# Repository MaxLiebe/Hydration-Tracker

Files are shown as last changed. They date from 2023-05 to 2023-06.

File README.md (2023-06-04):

# DIYCie Hydration Tracker
A device that can keep track of your hydration! 
It uses a 1kg load cell to detect the presence (and possibly fullness) of one's glass or bottle, and can perform various actions based on that. 
The main feature for the Hydration Tracker is keeping track of the time it takes for one to down their drink. The current list of planned and completed features is as follows:

- [X] Successfully detect the presence of a glass, and start/stop the timer accordingly.
- [X] Using the button on the front, allow the user to select different modes (e.g. down a bottle, down a glass, down a bottle of Smirnoff Ice, etc.)
- [X] Different LED ring animations depending on which mode.
- [ ] Allow the user to save the time it took to down a drink in a leaderboard.
- [X] Host a web page for entering a leaderboard score.
- [ ] Detect how full a glass is for games like "Pannetje-Pannetje" or a "Pitcheradt" (likely difficult to implement)

More features may be implemented if the hardware allows it! If you have any suggestions, please suggest them as an [issue](https://github.com/MaxLiebe/Hydration-Tracker/issues/new).

# Installation
For the installation instructions, please refer to the manual hosted on the Proto wiki. (no link yet).

# List of components
Please find the list of components in the manual (no link yet).

# 3d printing
The 3d printed units used can be found in the .stl folder. For the workshop, they were printed using 10% infill, PLA and no support.

# Acknowledgement and inspiration
This project was inspired by the Enschede-famous [AdtMeister](https://adtmeister.com/). DIYCie or S.A. Proto does not have any affiliations with AdtMeister.

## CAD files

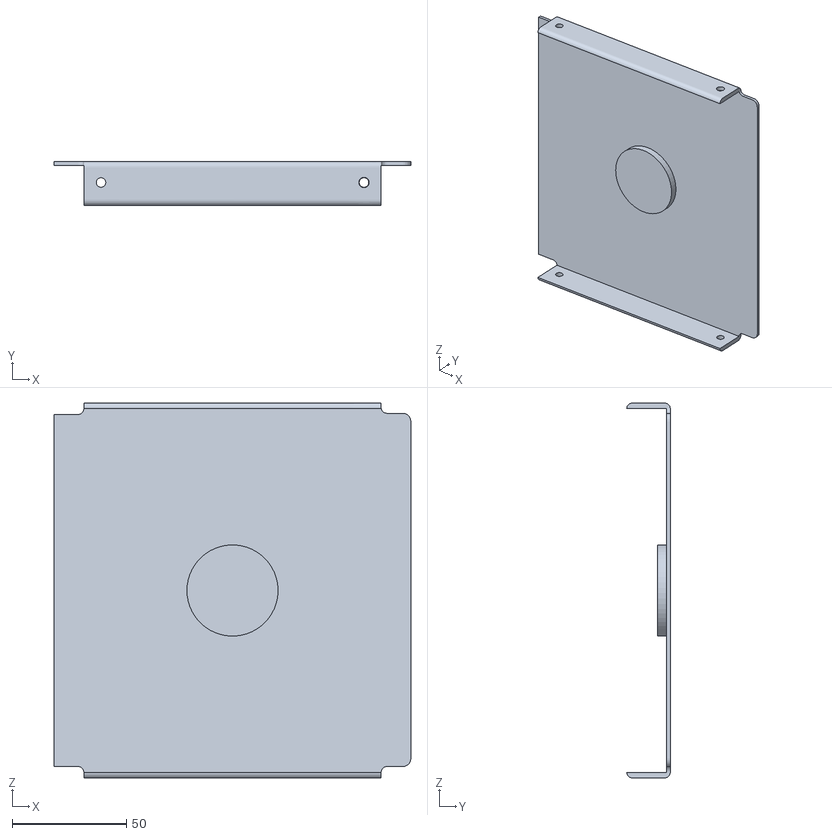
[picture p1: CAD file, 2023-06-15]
stl/cap.stl
156.0 x 19.1 x 164.0

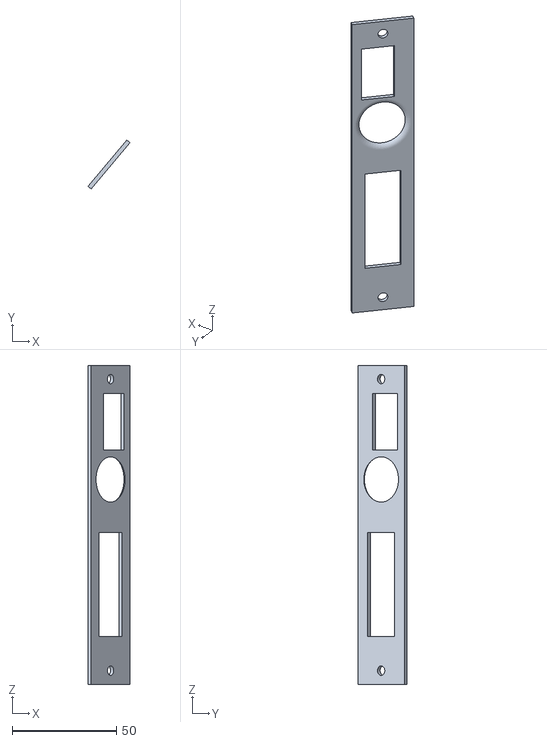
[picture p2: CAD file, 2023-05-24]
stl/front-cover.stl
20.2 x 23.5 x 153.0

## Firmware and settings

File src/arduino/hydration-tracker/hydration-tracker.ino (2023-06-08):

//IMPORT LIBRARIES
#include <FastLED.h>
#include "HX711.h"
#include <TM1637Display.h>
#include <Wire.h>
#include <SSD1306.h>
#include <qrcodeoled.h>
#include <WiFi.h>
#include <AsyncTCP.h>
#include <ESPAsyncWebServer.h>
#include "DNSServer.h"
#include "FS.h"
#include "SD.h"
#include "SPI.h"
#include <EEPROM.h>

#include "fonts.h"
#include "logo.h"

//Use debug mode?
//#define DEBUG //uncomment if you want to use debug mode (for calibration)

//SCREEN
#define SCREEN_ADDRESS 0x3C
#define OLED_SDA 17
#define OLED_SCK 16
SSD1306 display(SCREEN_ADDRESS, OLED_SDA, OLED_SCK, GEOMETRY_128_64);
QRcodeOled qrcode(&display);

//LED RING
#define RING_DATA_PIN 14
#define LED_TYPE WS2812B
#define COLOR_ORDER GRB
#define NUM_LEDS 24
#define BRIGHTNESS 200
#define MIN_BRIGHTNESS 0
CRGB ringLeds[NUM_LEDS];

//LOAD CELL
#define HX711_SCK 5
#define HX711_DT 3
#define LOAD_CELL_THRESHOLD 75000 //can be calibrated yourself. we'd recommend leaving it at this value
#define LOAD_CELL_CALIBRATED_VALUE -330000 //same as above
HX711 loadCell;

//TIMER
#define TIMER_CLK 2
#define TIMER_DIO 1
TM1637Display timer(TIMER_CLK, TIMER_DIO);
uint8_t TIMER_BLANK[4];

//SD Card
#define SD_CS_PIN        12
#define SD_CLK_PIN       11
#define SD_MOSI_PIN      9
#define SD_MISO_PIN      7
#define SD_FREQ          80000000
SPIClass spi = SPIClass(HSPI);

//MODE BUTTON
#define MODE_BUTTON_PIN 21

//TIMER MODES
#define SECONDS_HUNDREDTHS 0
#define MINUTES_SECONDS 1

//TIMER STATES
#define BOOTING -1
#define WAITING_FOR_THRESHOLD 0
#define THRESHOLD_REACHED 1
#define TIMER_RUNNING 2
#define TIMER_STOPPED 3

#define BOOT_TIME 4000
#define ONE_MINUTE 60000
#define MINIMUM_TIME 700

//ANIMATION STATES
#define ANIMATION_BOOT 0
#define ANIMATION_IDLE 1
#define ANIMATION_TIMER_PRIMED 2
#define ANIMATION_TIMER_STARTED 3
#define ANIMATION_TIMER_RUNNING 4
#define ANIMATION_TIMER_STOPPED 5
#define ANIMATION_MODUS_STATE 6

#define ANIMATION_SPEED_DRINKING 25
#define BRIGHTNESS_STEP_DRINKING 15

#define PULSE_DURATION 1000  // Duration of the pulse in milliseconds

//EEPROM
#define EEPROM_SIZE 4 //4 bytes to save the calibrated value long

//MODE STATES
#define NUMBER_OF_MODES 3
const String modes[NUMBER_OF_MODES] = {
  "beer_glass", "beer_rietadt", "ice"
};
const String modeNames[NUMBER_OF_MODES] = {
  "Beer out \n of glass", "Beer with \n straw", "Schmirnoff \n Ice"
};
const uint32_t modeColors[NUMBER_OF_MODES] = {
  CRGB::Yellow, CRGB::Green, CRGB::LightBlue
};

//WIFI CREDENTIALS FOR LEADERBOARD
const char* ssid = "HydrationTracker";
const char* password = ""; //optional, more effort for drunk people tho
#define LOCAL_IP_URL "http://4.3.2.1"

//WIFI SERVER
AsyncWebServer server(80);
DNSServer dnsServer;
String header;

//VARIABLES
unsigned long timerStartedMs = 0;
unsigned long timeElapsed = 0;
unsigned long animationStarted = 0;
int timerState = BOOTING;
int modeState = 0;
int animationState = ANIMATION_BOOT;
bool leaderboardEnabled = true;

bool pulseActive = true;
bool canSwitchMode = true;
bool showQR = false;
String drinkStatus = "Waiting for drink";

unsigned long lastDebounceTime = 0;  // the last time the output pin was toggled
unsigned long debounceDelay = 200;   // the debounce time; increase if the output flickers

// Define the current brightness and pulsation direction
uint8_t minBrightnessDrinking = MIN_BRIGHTNESS;
int8_t pulsationDirectionDrinking = 1;

// Define variables for timing
unsigned long previousMillisDrinking = 0;
unsigned long intervalDrinking = ANIMATION_SPEED_DRINKING;

void setup() {
  Serial.begin(9600);
  //initialize the LED ring with FastLED, and turn off all the LEDs
  FastLED.addLeds<LED_TYPE, RING_DATA_PIN, COLOR_ORDER>(ringLeds, NUM_LEDS).setCorrection(TypicalLEDStrip);
  FastLED.setBrightness(BRIGHTNESS);
  FastLED.clear();
  FastLED.show();

  //initialize the load cell
  loadCell.begin(HX711_DT, HX711_SCK);

  //initialize the 7 segment timer
  timer.setBrightness(0xff);
  encodeMsToTimer(0);

  //set the button to use the inbuilt pullup resistor
  pinMode(MODE_BUTTON_PIN, INPUT_PULLUP);

  //init and clear the display
  Wire.begin(OLED_SDA, OLED_SCK);
  display.setColor(WHITE);
  display.setFont(Roboto_Black_14);
  display.init();
  qrcode.init();
  display.clear();

  //show the splash screen
  display.drawXbm(0, 0, LOGO_WIDTH, LOGO_HEIGHT, LOGO_BITS);
  display.flipScreenVertically();
  display.display();

  //setup sd card
  spi.begin(SD_CLK_PIN, SD_MISO_PIN, SD_MOSI_PIN, SD_CS_PIN); 
  if (!SD.begin(SD_CS_PIN, spi, SD_FREQ)) {
    //SD card initialisation failed, don't bother with setting up a wifi hotspot.
    leaderboardEnabled = false;
    return;
  }

  //setup wifi access point
  WiFi.mode(WIFI_STA);
  IPAddress Ip(4, 3, 2, 1);
  IPAddress NMask(255, 255, 255, 0);
  WiFi.softAPConfig(Ip, Ip, NMask);
  WiFi.softAP(ssid, password);
  IPAddress IP = WiFi.softAPIP();

  dnsServer.start(53, "*", IP);
  server.on("/", HTTP_GET, [](AsyncWebServerRequest *request){
    //request->send(200, "text/plain", "Hello, world");
    request->send(SD, "/index.html", "text/html");
  });
  server.on("/generate_204", [](AsyncWebServerRequest *request) { request->redirect(LOCAL_IP_URL); });
  server.on("/redirect", [](AsyncWebServerRequest *request) { request->redirect(LOCAL_IP_URL); });			   // microsoft redirect
	server.on("/hotspot-detect.html", [](AsyncWebServerRequest *request) { request->redirect(LOCAL_IP_URL); });  // apple call home
	server.on("/canonical.html", [](AsyncWebServerRequest *request) { request->redirect(LOCAL_IP_URL); });	   // firefox captive portal call home
	server.on("/success.txt", [](AsyncWebServerRequest *request) { request->send(200); });					   // firefox captive portal call home
	server.on("/ncsi.txt", [](AsyncWebServerRequest *request) { request->redirect(LOCAL_IP_URL); });			   // windows call home
  server.serveStatic("/", SD, "/");
  
  server.begin();
}

void loop() {
  #ifndef DEBUG
  if(!showQR) {
    display.setTextAlignment(TEXT_ALIGN_CENTER);
    display.clear();
    display.drawString(64, 12, drinkStatus);
    display.drawString(64, 30, "Mode: " + modeNames[modeState]);
    display.display();
  }
  #endif

  if ((millis() - lastDebounceTime) > debounceDelay) {
    if (digitalRead(MODE_BUTTON_PIN) == 0) {
      if(timerState == TIMER_STOPPED) {
        timerState = WAITING_FOR_THRESHOLD;
        animationState = ANIMATION_IDLE;
        canSwitchMode = true;
        lastDebounceTime = millis();
        showQR = false;
      }else if(canSwitchMode){
        lastDebounceTime = millis();  //set the current time
        modeState += 1;
        animationStarted = millis();
        animationState = ANIMATION_MODUS_STATE;
        showQR = false;
      }
    }
  }
  if (modeState > NUMBER_OF_MODES - 1) {
    modeState = 0;
  }

  switch (timerState) {
    case BOOTING:
      canSwitchMode = true;
      if (millis() > BOOT_TIME) {
        timerState = WAITING_FOR_THRESHOLD;
        animationState = ANIMATION_IDLE;
        switch(SD.cardType()) {
          case CARD_NONE: {
            display.drawString(64, 50, "No SD card found");
            leaderboardEnabled = false;
            break;
          }
        }
        display.display();
      }
      break;
    case TIMER_RUNNING:
      timeElapsed = millis() - timerStartedMs;
      if(timeElapsed > MINIMUM_TIME) encodeMsToTimer(timeElapsed);
      break;
  }

  if (loadCell.is_ready()) {
    int weightValue = loadCell.get_value(1);
    #ifdef DEBUG
    display.clear();
    display.setTextAlignment(TEXT_ALIGN_LEFT);
    display.drawString(0, 6, String(weightValue));
    display.display();
    #endif

    //becomes true if something is detected on the load cell (the weight is above the threshold)
    bool thresholdMet = LOAD_CELL_CALIBRATED_VALUE - weightValue < -LOAD_CELL_THRESHOLD || LOAD_CELL_CALIBRATED_VALUE - weightValue > LOAD_CELL_THRESHOLD;

    switch (timerState) {
      case WAITING_FOR_THRESHOLD:
        if (thresholdMet && millis() - lastDebounceTime > debounceDelay) {
          canSwitchMode = false;
          lastDebounceTime = millis();
          timerState = THRESHOLD_REACHED;
          animationState = ANIMATION_TIMER_PRIMED;
          animationStarted = millis();
          encodeMsToTimer(0);
          drinkStatus = "Ready?";
          showQR = false;
        }
        break;
      case THRESHOLD_REACHED:
        if (!thresholdMet && millis() - lastDebounceTime > debounceDelay) {
          timerState = TIMER_RUNNING;
          timerStartedMs = millis();
          canSwitchMode = false;
          animationState = ANIMATION_TIMER_RUNNING;
          drinkStatus = "Go!";
        }
        break;
      case TIMER_RUNNING:
        if (thresholdMet) { 
          if(millis() - timerStartedMs >= MINIMUM_TIME) {
            timerState = TIMER_STOPPED;
            animationState = ANIMATION_TIMER_STOPPED;
            animationStarted = millis();
            drinkStatus = "Waiting for drink";
            if(leaderboardEnabled) {
              char secret[10];
              generateRandomDigits(secret, 10);
              char url[100];
              sprintf(url, "http://4.3.2.1?t=%i&s=%.10s", timeElapsed, secret);
              qrcode.create(url);
              showQR = true;
            }
          }
        }
        break;
    }
  }

  //switch statement to manage what animation is being displayed on the LED ring
  switch (animationState) {
    case ANIMATION_MODUS_STATE:
      {
        if (millis() - animationStarted > debounceDelay * 2) {
          animationState = ANIMATION_IDLE;
        }
        modusSwitch();
        break;
      }
    case ANIMATION_BOOT:
      {
        bootAnimation();
        break;
      }
    case ANIMATION_IDLE:
      {
        idleRingAnimation();
        break;
      }
    case ANIMATION_TIMER_PRIMED:
      {
        timerPrimedAnimation();
        break;
      }
    case ANIMATION_TIMER_RUNNING:
      {
        timerRunningAnimation();
        break;
      }
    case ANIMATION_TIMER_STOPPED:
      {
        timerStoppedAnimation();
        break;
      }
  }

  dnsServer.processNextRequest(); 
}

void encodeMsToTimer(unsigned long ms) {
  //create an array to store the digits in
  uint8_t segments[4];

  //decide what mode to use for the timer based on how much time has elapsed
  int timerMode = ms < ONE_MINUTE ? SECONDS_HUNDREDTHS : MINUTES_SECONDS;

  //timerMode is an int, so we'll use a switch statement to accomodate for different modes
  //for expandability, we have opted not to just use a boolean here
  switch (timerMode) {
    case SECONDS_HUNDREDTHS:
      //extract the seconds and the hundredths from the milliseconds
      int seconds = ms / 1000;
      int hundredths = (ms - (seconds * 1000)) / 10;

      //update the segments with the correct digits
      segments[0] = timer.encodeDigit(seconds / 10);
      segments[1] = timer.encodeDigit(seconds % 10) | 0x80;  //OR-ing with 0x80 to turn on the :
      segments[2] = timer.encodeDigit(hundredths / 10);
      segments[3] = timer.encodeDigit(hundredths % 10);
      break;
  }
  timer.setSegments(segments);
}

void generateRandomDigits(char* buf, int l) {
  for(int i = 0; i < l; i++) {
    byte randomValue = random(0, 10);
    char letter = randomValue + '0';
    buf[i] = letter;
  }
}

void bootAnimation() {
  //fade in and out the green LED ring
  FastLED.clear();
  unsigned long currentTime = millis();
  int fadeValue = 255 - (float)(abs((int)currentTime % 1000 - 500) / 500.0 * 255);
  fill_solid(ringLeds, NUM_LEDS, CRGB::Green);
  fadeToBlackBy(ringLeds, NUM_LEDS, fadeValue);
  FastLED.show();
}

void idleRingAnimation() {
  //show a snake of x LEDs going round with a certain speed
  FastLED.clear();
  int trailLeds = 20;
  int snakeSpeed = 24;  //LEDs per second
  unsigned long currentTime = millis();
  int currentPosition = (currentTime / (1000 / snakeSpeed)) % NUM_LEDS;
  for (int i = 0; i < trailLeds; i++) {
    int led = (currentPosition - i + NUM_LEDS) % NUM_LEDS;
    ringLeds[led] = modeColors[modeState];
    byte fade = map(i, 0, trailLeds, 0, 255);
    ringLeds[led].fadeToBlackBy(fade);
  }
  FastLED.show();
}

void timerPrimedAnimation() {
  //pulsing animation with a set speed
  int pulseDuration = 300;

  FastLED.clear();
  unsigned long time = millis() - animationStarted;
  uint8_t brightness = (int)((float)(time % pulseDuration) / (float)pulseDuration * 255.0);
  fill_solid(ringLeds, NUM_LEDS, modeColors[modeState]);
  fadeToBlackBy(ringLeds, NUM_LEDS, 255 - brightness);
  FastLED.show();
}

void timerRunningAnimation() {
  // Check if it's time to update the animation
  unsigned long currentMillisDrinking = millis();
  if (currentMillisDrinking - previousMillisDrinking >= intervalDrinking) {
    previousMillisDrinking = currentMillisDrinking;

    // Update the brightness
    minBrightnessDrinking += pulsationDirectionDrinking * BRIGHTNESS_STEP_DRINKING;

    // Set the LED colors
    fill_rainbow(ringLeds, NUM_LEDS, minBrightnessDrinking);

    // Show the updated LED array
    FastLED.show();
  }
}

void timerStoppedAnimation() {
  //a fast-fading WHOOSH that then fades out

  int rampUpTime = 200;
  int fadeOutTime = 400;

  FastLED.clear();
  unsigned long time = millis() - animationStarted;
  uint8_t brightness;
  if(time <= rampUpTime) {
    brightness = map(time, 0, rampUpTime, 0, 255);
  }else if(time <= rampUpTime + fadeOutTime){
    brightness = 255 - map(time, rampUpTime, rampUpTime + fadeOutTime, 0, 255);
  }else{
    brightness = 0;
  }
  
  fill_solid(ringLeds, NUM_LEDS, modeColors[modeState]);
  fadeToBlackBy(ringLeds, NUM_LEDS, 255 - brightness);

  FastLED.show();
}

void modusSwitch() {
  unsigned long elapsedTime = millis() - animationStarted;
  // Calculate the brightness based on the elapsed time
  uint8_t brightness = map(elapsedTime, 0, PULSE_DURATION, 0, 255);
  // Apply the red color and brightness to all LEDs
  fill_solid(ringLeds, NUM_LEDS, CRGB(brightness, 0, 0));
  FastLED.show();
}

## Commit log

2023-05-24 Improved file structure
    [cap.stl, front-cover.stl]
2023-05-30 Rewrote timer system to use states instead of a shit ton of booleans, also implemented different timer modes
2023-05-30 Calibrated load cell value to 17000 (should be fine for now)
2023-05-31 Modus switch button added
2023-06-03 basic leaderboard functionality working (without categories). needs to be implemented in arduino still.
2023-06-04 simple modus switch with new animations
2023-06-08 Pretty much the fix of all fixes
    [hydration-tracker.ino]
2023-06-08 Fix random extra characters for the qr code url. Adjusted the threshold
    [hydration-tracker.ino]
